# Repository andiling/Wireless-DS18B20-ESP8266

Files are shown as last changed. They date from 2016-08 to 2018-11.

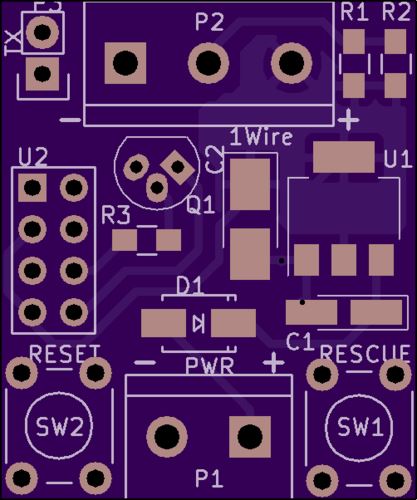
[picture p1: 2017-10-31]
img/pcb.jpg

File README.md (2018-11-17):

# ---->Moved to Domochip/Wireless-DS18B20-Bus<----
----> https://github.com/Domochip/Wireless-DS18B20-Bus <----

# WirelessDS18B20

This project use an ESP8266 and some DS18B20 sensors on a 1-Wire bus to provide temperatures in JSON format (Jeedom compatible).

The global idea of this project is that any system (like Jeedom) that's able to do an HTTP GET request and interpret JSON will get list of DS18B20 ROMcode available on buses or current temperature of a DS18B20 sensor.

getList getTemp

## Build your 1-Wire bus

In order to get a wide 1-Wire bus (one that cover a house), Dallas provides some recommendations into their application note AN148.

This project use the Improved Interface bellow that is able to support a 200m bus:

Dallas AN148 ImprovedCPUBusInterface schema

This one requires a pin for reading the bus state and another one as output to drive the bus low : I named it the "Dual Pin OneWire"

**Warning : If you build a large 1 Wire bus inside your house, keep in mind that some high voltage may appear on this one by induction. You need to have a good knowledge about electricity and associated risks!!!**

## Build your WirelessDS18B20

All files are inside schematic subfolder and has been designed with KiCad

### Schematic

WirelessDS18B20 schematic

### PCB

WirelessDS18B20 PCB

### Code/Compile

Source code can be compiled for :

- ESP-01 : Pin usage is fixed like in schematic.
- other ESP8266 models : 1-Wire buses pins can be configured through the configuration webpage

In order to compile you first need to run PowerShell script which is in htmlToCppHeader folder.
This one compress and then convert into code (PROGMEM variables) the webpages files (into data folder)

## Run

### First Boot

During First Boot, the ESP boot in Access Point Mode to allow you configuration

- Network SSID : `WirelessDS18B20`
- Password : `PasswordDS18B20`
- ESP IP : `192.168.4.1`

Connect to this network and then configure it.

### Configuration

WirelessDS18B20 offers you some webpages in order to configure it :

- `http://IP/` return you the current status of the module :

status screenshot

- `http://IP/config` allows you to change configuration (Wifi and 1-Wire buses (only non-ESP01)) :

config screenshot

- **ssid & password** : IDs of your Wifi Network
- **hostname** : name of ESP on the network
- **IP,GW,NetMask,DNS1&2** : Fixed IP configuration
- **number of OneWire buses** : number of OneWire buses...
- **buses pin numbers** : pins for each oneWire buses (2 pins per OW bus)

- `http://IP/fw` allows you to flash a new firmware version :

firmware screenshot

### Rescue Mode

If you lost access to your WirelessDS18B20, you can `reset it` (reset button or power off) and during the 5 first seconds, `press the "Rescue Mode" button` to start it with default config (like during First Boot).

## Use it

### Basics

Usage (answers are in JSON format):

- `http://IP/getList?bus=0` will return list of DS18B20 ROMCodes available on the 1-Wire bus number 0
- `http://IP/getTemp?bus=0&ROMCode=0A1B2C3D4E5F6071` will return simple JSON with temperature from the sensor

### With Jeedom

> Memento : Jeedom is an innovative home automation system that can be found at <http://jeedom.com>

For this configuration you need the *Script* plugin installed from the market :

Script Icon

Go to script plugin then add a new equipment:

Script Add

Name it :

Script Name

Set refresh time (every minutes in my case) :

Script Refresh

Then into command tab, add a script command :

Script Command

Then set it up with :

- command name : Temperature
- script type : JSON
- request : Temperature (JSON tag name)
- URL : <http://***IP***/getTemp?bus=***0***&ROMCode=***0A1B2C3D4E5F6071***>
- Unit : °C

Script Command Config

Now you're done and should get something like this :

Script Command Result

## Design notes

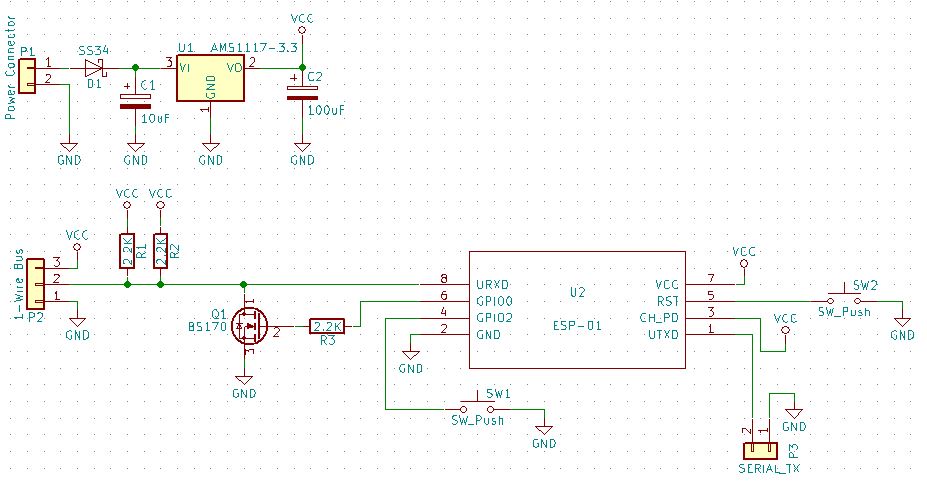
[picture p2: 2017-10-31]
img/schematic.jpg

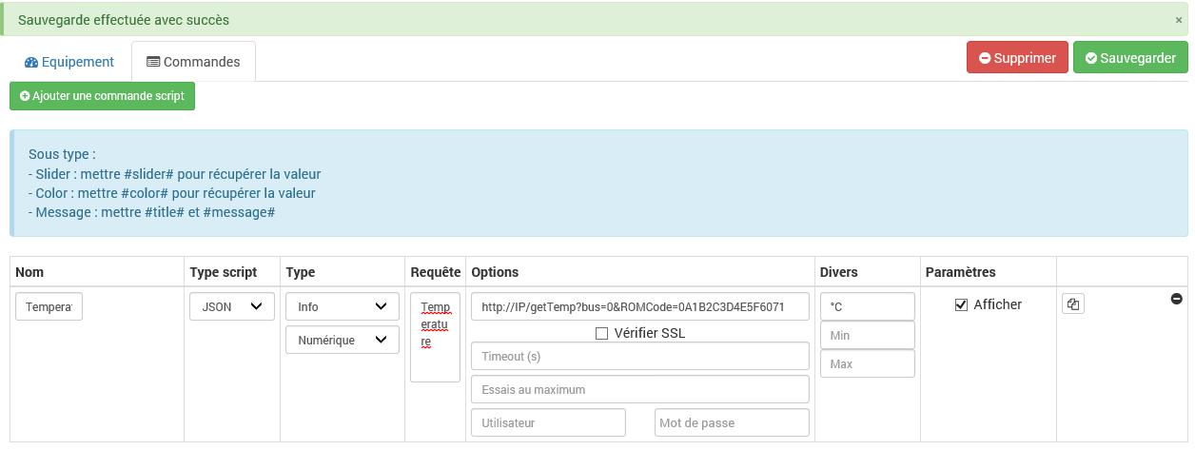
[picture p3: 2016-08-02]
img/JeedomScriptCmdConfig.png

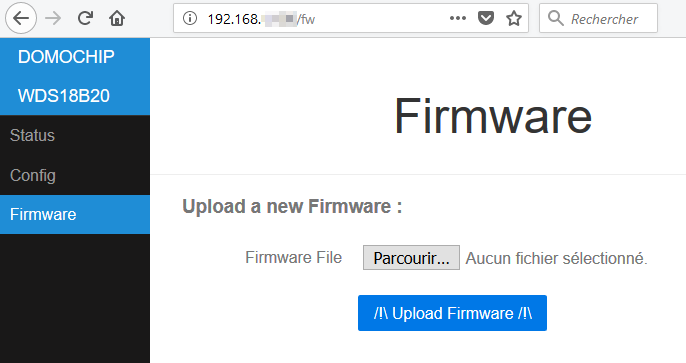
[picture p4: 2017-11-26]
img/firmware.png

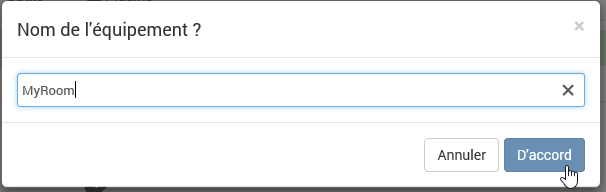
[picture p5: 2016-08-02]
img/JeedomScriptName.png

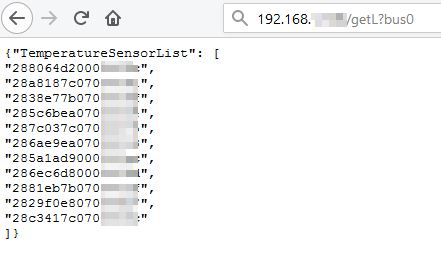
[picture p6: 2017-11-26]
img/getL.jpg

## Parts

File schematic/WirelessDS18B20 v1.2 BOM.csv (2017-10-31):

Item | Qty needed
Diode SS34 SMD Type A | 1
C 100uF SMD type B | 1
C 10uF SMD Type A | 1
AMS1117 3.3V | 1
Terminal Block KF301-5.0-2P | 1
Terminal Block KF301-5.0-3P | 1
R 2.2K SMD 0805 | 3
BS170 | 1
Micro Switch 6*6*5mm | 2
breakaway Male header x40 | 1
Double Row 2X4 Pin 8P 2.54Mm Female Straight | 1
ESP-01 | 1
PCB Wireless DS18B20 v1.2 25 | 4mmx30 | 5mm | 1

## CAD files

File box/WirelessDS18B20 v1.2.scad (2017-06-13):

use <utils/build_plate.scad>

_part = "box"; // [box, lid, both]

_innerDimensions = true;


//PCB dimensions
_pcbX = 30.5;
_PCBy = 25.4;

// width of the box (affects the length of the hinges)
_width = 31; // [10:300]

// length of the box
_length = 26; // [10:300]

// height of the box
_height = 18; // [4:300]

// rounding radius of the corners of the box
_rounding = 4; // [1:50]

// thickness of the walls around the magnets
_minimumWallThickness = 0.5;

// thickness of the side walls without the hinge
_sidewallThickness = 1.5;

// thickness of the bottom of the box or the top of the lid
_horizontalThickness = 1.25;

// diameter of magnets in the hinge
_magnetDiameter = 2.5;

// height magnets in the hinge
_magnetHeight = 1;

// gap bewteen the lid and box parts
_hingeGap = 0.4;

// Size of lid's spheres that go into box holes
_hingeOverlap = 0.15;

_lidRadius = 0;

module roundRect(width, depth, height, round) {
	round = min(round, width/2);
	linear_extrude(height=height,center=true) offset(r=round) square([width-2*round,depth-2*round],center=true);
}

module roundRectFillet(width, depth, height, round, radius) {
    
    radius=max(0.00001,radius);
    
    minkowski(){
        union(){
            
            translate([0,0,(height-radius)/2])cylinder(r=radius,h=height-radius,center=true);
                
            translate([0,0,height-(radius>height?height:radius)])
            resize([0,0,radius>height?height:0])
            difference(){
                sphere(r=radius, center=true);
                translate([0,0,-radius/2]) cube([2*radius,2*radius,radius],center=true);
            }
        }
    
        roundRect(width-(2*radius),depth-(2*radius),0.000001,round);
    }
}

module makeBase(width, depth, height, rounding, minimum, side, bottom, mdiameter, mheight, gap) {
	eps = 0.1;
	iwidth = width - side*2;
	idepth = depth - mdiameter*2 - minimum*4;
	hingeCutZ = mdiameter + minimum*2/* + gap*/;
	hingeCutWidth = width - rounding*2 - mheight*2;
	fillet = mdiameter/2 + minimum;

    union(){
        difference() {
            translate([0,0,height/2]) 
            difference() {
                roundRect(width, depth, height, rounding);
                translate([0,0,bottom]) {
                    //roundRect(iwidth, idepth, height, rounding-side);
                    cube(size=[iwidth, idepth, height],center=true);
                }
            }
            
    
            // hinge cutout
            translate([0,0,height - hingeCutZ/2 + eps/2]) {
                cube(size=[hingeCutWidth, depth+eps, hingeCutZ + eps], center=true);
            }
            
            // sphere cutout
            for (x=[-1,1])
            for (y=[-1,1]) {
                translate([x * (hingeCutWidth/2 - eps/2), y*(depth/2 - minimum - mdiameter/2), height - minimum - mdiameter/2])
                sphere(d=mdiameter);
            }

            //WirelessDS18B20 bornier Cutout
            //bornier2
            translate([iwidth/2,-4-0.5-0.3,bottom+4/*4mm from bottom*/])cube([(width-iwidth)/2,4,6]);
            translate([iwidth/2,+0.5-0.3,bottom+4/*4mm from bottom*/])cube([(width-iwidth)/2,4,6]);

            //bornier3
            translate([-width/2,1+4/2,bottom+4/*4mm from bottom*/])cube([(width-iwidth)/2,4,6]);
            translate([-width/2,-4/2,bottom+4/*4mm from bottom*/])cube([(width-iwidth)/2,4,6]);     
            translate([-width/2,-4-2-1,bottom+4/*4mm from bottom*/])cube([(width-iwidth)/2,4,6]);

            //WirelessDS18B20 Texts
            //bornier2
            translate([width/2-0.5,-0.3,1])rotate([90,0,90])linear_extrude(0.5)text(text="PWR",font="Liberation Sans:style=Bold",size=3.5,halign="center");
            translate([width/2-0.5,-0.3-7.5,7.2])rotate([90,0,90])linear_extrude(0.5)text(text="-",font="Liberation Sans:style=Bold",size=6,halign="center");
            translate([width/2-0.5,-0.3+7.5,7])rotate([90,0,90])linear_extrude(0.5)text(text="+",font="Liberation Sans:style=Bold",size=6,halign="center");


            //bornier3
            translate([-width/2+0.5,0,1])rotate([90,0,-90])linear_extrude(0.5)text(text="1WIRE",font="Liberation Sans:style=Bold",size=3.5,halign="center");
            translate([-width/2+0.5,-8.4,10.2])rotate([90,0,-90])linear_extrude(0.5)text(text="-",font="Liberation Sans:style=Bold",size=5.5,halign="center");
            translate([-width/2+0.5,0,12])rotate([90,0,-90])linear_extrude(0.5)text(text="DATA",font="Liberation Sans:style=Bold",size=2.2,halign="center");
            translate([-width/2+0.5,8.4,9.7])rotate([90,0,-90])linear_extrude(0.5)text(text="+",font="Liberation Sans:style=Bold",size=5.5,halign="center");

        }

        //WirelessDS18B20 additions
        translate([-iwidth/2,-idepth/2,bottom])linear_extrude(2)polygon([[0,0],[0,3.5],[3.5,0]]);
        translate([-iwidth/2,idepth/2,bottom])linear_extrude(2)polygon([[0,0],[0,-3.5],[3.5,0]]);

        translate([_pcbX/2-3-3.5,idepth/2-6,bottom])cube([3,6,2]);
        translate([_pcbX/2-3-3.5,-idepth/2,bottom])cube([3,6,2]);

    }
}


module makeLid(width, depth, rounding, minimum, side, bottom, mdiameter, mheight, gap, overlap) {
	eps = 0.1;
	hingeWidth = width - rounding*2 - mheight*2 - gap*2;
	hingeSize = mdiameter + minimum*2;
    
    //WirelessDS18B20
    idepth = depth - mdiameter*2 - minimum*4;
	
	difference() {
		union() {
			translate([0,0,bottom/2]) {
				roundRect(width, depth, bottom, rounding);
			}	

			// hinges
			for (s=[-1,1]) {
				translate([0,s*(depth/2 - hingeSize/2),bottom + hingeSize/2]) {
					hull() {
						rotate([0,90,0]) {
							cylinder(r=hingeSize/2, h=hingeWidth,center=true);
						}
						translate([0,s*-hingeSize/4,0]) {
							cube(size=[hingeWidth, hingeSize/2, hingeSize], center=true);
						}
						translate([0,0,-hingeSize/4-eps]) {
							cube(size=[hingeWidth, hingeSize, hingeSize/2], center=true);
						}
					}
				}
			}
            // sphere additions
            for (x=[-1,1])
            for (y=[-1,1]) {
                translate([x * (hingeWidth/2 - eps), y*(depth/2 - minimum - mdiameter/2), mdiameter/2 + bottom + minimum]){
                    difference(){
                        sphere(d=mdiameter);
                        translate([x*(mdiameter/2+eps+gap+overlap),0,0]) cube([mdiameter,mdiameter,mdiameter],center=true);
                    }
                }
            }
            
            //WirelessDS18B20 Additions
            //buttons
            translate([-_pcbX/2+4.5,-9.1-0.3,0])cylinder(d=6.5,h=10.5+bottom);
            translate([-_pcbX/2+4.3,9.3-0.3,0])cylinder(d=6.5,h=10.5+bottom);

		}


        //WirelessDS18B20 cutouts
        //buttons
        translate([-_pcbX/2+4.5,-9.1-0.3,0])cylinder(d=4,h=10.5+bottom);
        translate([-_pcbX/2+4.3,9.3-0.3,0])cylinder(d=4,h=10.5+bottom);

        //bornier2
        translate([-_pcbX/2+3.81,2.5-0.3,0])cylinder(d=4.5,h=bottom);
        translate([-_pcbX/2+3.81,-2.5-0.3,0])cylinder(d=4.5,h=bottom);

        //bornier3
        translate([+_pcbX/2-3.3,5,0])cylinder(d=4.5,h=bottom);
        translate([+_pcbX/2-3.3,0,0])cylinder(d=4.5,h=bottom);
        translate([+_pcbX/2-3.3,-5,0])cylinder(d=4.5,h=bottom);

        //ESP leds
        translate([-_pcbX/2+9.6,5.6-0.3,0.25])cylinder(d=1.5,h=bottom-0.25);
        //translate([-_pcbX/2+9.6,5.6-0.3,0])cylinder(d=1.5,h=0.5);
        translate([-_pcbX/2+12.6,5.6-0.3,0.25])cylinder(d=1.5,h=bottom-0.25);
        //translate([-_pcbX/2+12.6,5.6-0.3,0])cylinder(d=1.5,h=0.5);

        //WirelessDS18B20 Texts
        //Bouttons
        translate([-3.5,-11,0.5])rotate([0,-180,-180])difference(){
            linear_extrude(0.6)offset(r=0.6)text(text="RST",font="Liberation Sans:style=Bold",size=3,halign="center");
            linear_extrude(0.6)text(text="RST",font="Liberation Sans:style=Bold",size=3,halign="center");
        }
        translate([-3.5,14,0.5])rotate([0,-180,-180])difference(){
            linear_extrude(0.6)offset(r=0.6)text(text="RSC",font="Liberation Sans:style=Bold",size=3,halign="center");
            linear_extrude(0.6)text(text="RSC",font="Liberation Sans:style=Bold",size=3,halign="center");
        }
        /*
        translate([-10,-13,0.5])rotate([0,-180,-180])linear_extrude(0.6)text(text="RST",font="Liberation Sans:style=Bold",size=3,halign="center");
        translate([-10,16,0.5])rotate([0,-180,-180])linear_extrude(0.6)text(text="RSC",font="Liberation Sans:style=Bold",size=3,halign="center");
        */
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

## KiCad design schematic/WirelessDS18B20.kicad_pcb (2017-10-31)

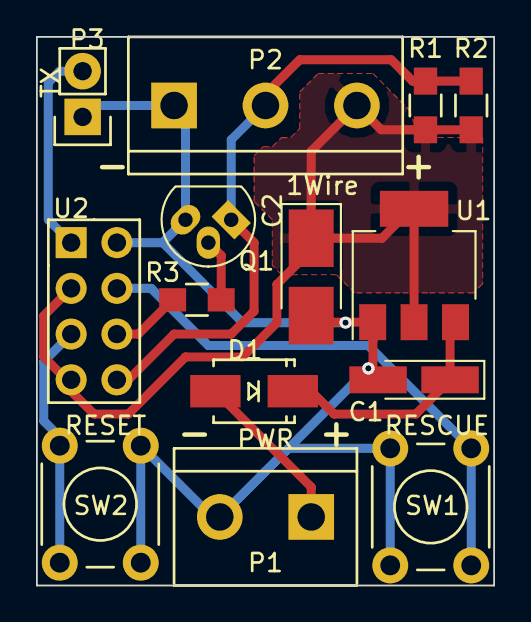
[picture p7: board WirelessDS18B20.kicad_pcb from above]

Board: 2 copper layers, 25.4 x 30.5 mm, 14 parts (0 on the bottom side), 10 nets.

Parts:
C1: 10uF; CP_Tantalum_Case-A_EIA-3216-18_Hand
C2: 100uF; CP_Tantalum_Case-B_EIA-3528-21_Hand
D1: SS34; SMA_Handsoldering_Custom
P1: Power Connector; bornier2
P2: 1-Wire Bus; bornier3
P3: SERIAL_TX; Pin_Header_Straight_1x02
Q1: BS170; TO-92_Molded_Narrow_Oval
R1, R2, R3: 2.2K; R_0805_HandSoldering
SW1, SW2: SW_Push; SW_PUSH_6mm
U1: AMS1117-3.3; SOT-223
U2: ESP-01

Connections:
GND: C1.2, C2.2, P1.2, P2.1, P3.1, Q1.3, SW1.2, SW2.2, U1.1, U2.2
unnamed: C1.1, D1.1, U1.3
unnamed: D1.2, P1.1
unnamed: P2.2, Q1.1, R1.2, R2.2, U2.8
unnamed: P3.2, U2.1
unnamed: Q1.2, R3.2
unnamed: R3.1, U2.6
unnamed: SW1.1, U2.4
unnamed: SW2.1, U2.5
VCC: C2.1, P2.3, R1.1, R2.1, U1.2, U2.3, U2.7

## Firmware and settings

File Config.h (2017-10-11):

#ifndef Config_h
#define Config_h

#include <ESP8266WiFi.h>
#include <ESPAsyncTCP.h>
#include <ESPAsyncWebServer.h>

#include "data\config.html.gz.h"

#define DEFAULT_AP_SSID "WirelessDS18B20"
#define DEFAULT_AP_PSK "PasswordDS18B20"

const char predefPassword[] PROGMEM = "ewcXoCt4HHjZUvY0";

#define MAX_NUMBER_OF_BUSES 4

class Config {
  public:
    char ssid[32 + 1] = {0};
    char password[64 + 1] = {0};
    char hostname[24 + 1] = {0};

    byte numberOfBuses = 0;
    uint8_t owBusesPins[MAX_NUMBER_OF_BUSES][2];

    void SetDefaultValues() {
      ssid[0] = 0;
      password[0] = 0;
      hostname[0] = 0;
      numberOfBuses = 0;
      memset(owBusesPins, 0, MAX_NUMBER_OF_BUSES * 2);
    }
    static byte AsciiToHex(char c); //Utils
    static bool FingerPrintS2A(byte* fingerPrintArray, const char* fingerPrintToDecode);
    static char* FingerPrintA2S(char* fpBuffer, byte* fingerPrintArray, char separator = 0);

    bool Save();
    bool Load();
    void InitWebServer(AsyncWebServer &server, bool &shouldReboot);
  private :
    String GetJSON();
    bool SetFromParameters(AsyncWebServerRequest* request);
    uint16_t crc; ///!\ crc should always stay in last position
};


#endif

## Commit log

2016-07-06 v1.1
    For larger 1-Wire bus, Improved Bus Interface is required. I named it
    Dual Pin 1-Wire
2016-08-02 Add Schematic
    [WirelessDS18B20.sch]
2016-08-08 Update Schematic
    [WirelessDS18B20.sch]
2016-08-22 Fix no Bus for ESP-01
    [WirelessDS18B20.ino]
2016-08-23 Improve loadConfig and print IP while starting
2016-08-23 Fix WiFi never connect after changes
    [WirelessDS18B20.ino]
2017-02-17 Implement Config class
    Switch from configuration global variables to Config class (that is
    stored into EEPROM)
2017-02-17 Improve performance for browser other than IE
    Use WiFiClient.write instead of WiFiClient.print (send multyple bytes
    per network packet...)
2017-02-17 Use dynamic WebPage store in SPIFFS
    Switch to ESPWebServer, return WebPage (using JQuery) stored in SPIFFS
    and minimize content generated by ESP to simple JSON datas
2017-02-20 Memory improvment, Web optimization
    getconfig has been replaced by status webpage (config is in config).
    SendHTTPShortAnswer became SendHTTPResponse.
    String has been used back to generate JSON code but reserve function has
    been used to reduce heap leak.
    etc... :-)
    [WirelessDS18B20.ino]
2017-02-22 V2.3 Config DefaultValue and rework on FindParam
    [Config.h, WirelessDS18B20.ino]
2017-03-09 Update Schematic (PCB now Provided)
    [WirelessDS18B20.kicad_pcb, WirelessDS18B20.sch]
2017-03-09 Update README.md
    describe new interface and update schematic and PCB
2017-03-31 Update Schematic
    Addition of power diode against bad connection + reduce board size
    [WirelessDS18B20.kicad_pcb, WirelessDS18B20.sch]
2017-03-31 Add Bill of Material for hobbyist
    [WirelessDS18B20 v1.2 BOM.xlsx]
2017-05-03 v2.3.5 - Improve WiFi management
    Improve WiFi management
    correct IE bug on fw pages
    reduce first delay to 200
    [Config.h, WirelessDS18B20.ino]
2017-06-13 Add OpenSCAD box for WirelessDS18B20
    Version Number corespond to PCB version number
    [WirelessDS18B20 v1.2.scad]
2017-10-11 V3.0
    switch to ESPAsyncWebServer from me-no-dev
    lot of improvement
2017-10-12 Switch to JQuery CDN by default (3.2.1)
2017-10-31 Improve Schematic (update KiCad to 4.0.7)
    [WirelessDS18B20 v1.2 BOM.csv, WirelessDS18B20 v1.2 BOM.xlsx, WirelessDS18B20.kicad_pcb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]
